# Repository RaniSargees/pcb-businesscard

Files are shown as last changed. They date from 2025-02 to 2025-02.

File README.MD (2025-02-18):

# PCB BUSINESS CARD

this project is a business card made of a circuit board with an 11x10 charlieplexed LED display.

The circuit board uses special construction techniques to achieve minimum thickness, such as mounting every component upside-down, through drilled holes.

this project is based on the HK32F030M microcontroller, which is obscure and poorly-documented (in english, at least), but very inexpensive

the total cost per card (purchased in medium-low volume) is ~$0.80CAD, which is high for a business card but still relatively cheap

# INCOMPLETE FIRMWARE

the firmware for this project is incomplete. the breakout game is unfinished, and I haven't even began working on pong, space invaders, and other games i wanted to add.

also, the font is a little unreadable on the display, which sort of defeats the purpose of this business card. I probably should have included my name and email in the silkscreen

---

still, uploading this for reference, perhaps someone can use this project as an example of how to set up keil for the hk32. that chip doesn't have much documentation, it seems everyone went for the risc-v based budget microcontrollers and not the ARM-based HK32 or PY32

# IMAGES

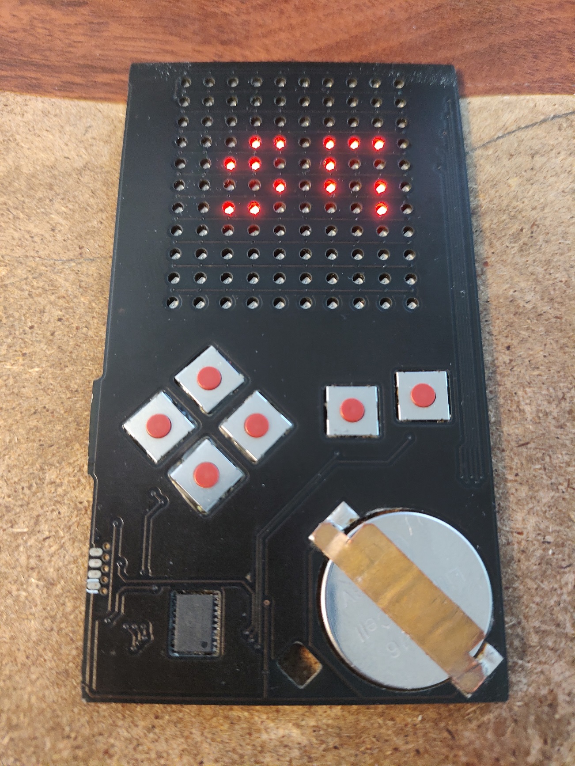
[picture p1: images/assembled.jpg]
assembled


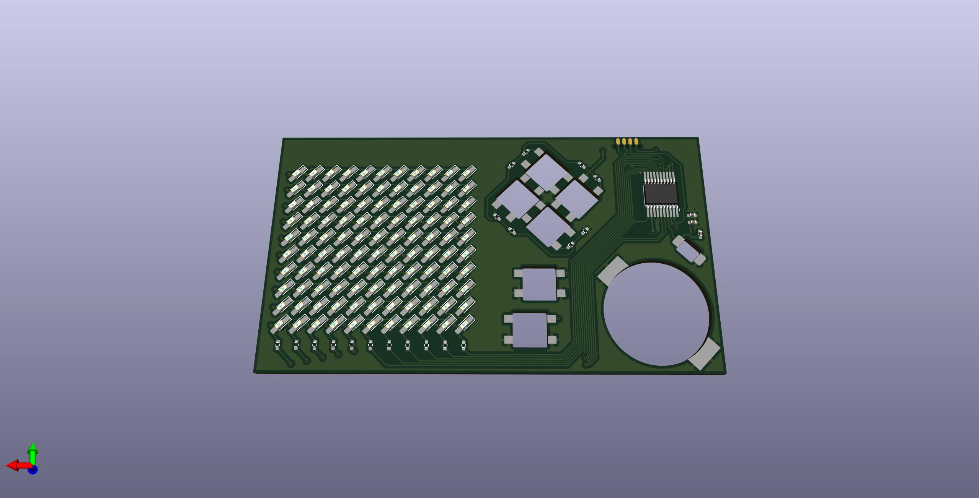
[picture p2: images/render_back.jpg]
back


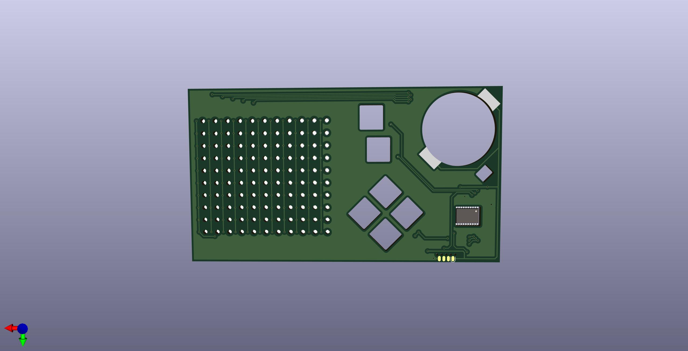
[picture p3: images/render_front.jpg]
front


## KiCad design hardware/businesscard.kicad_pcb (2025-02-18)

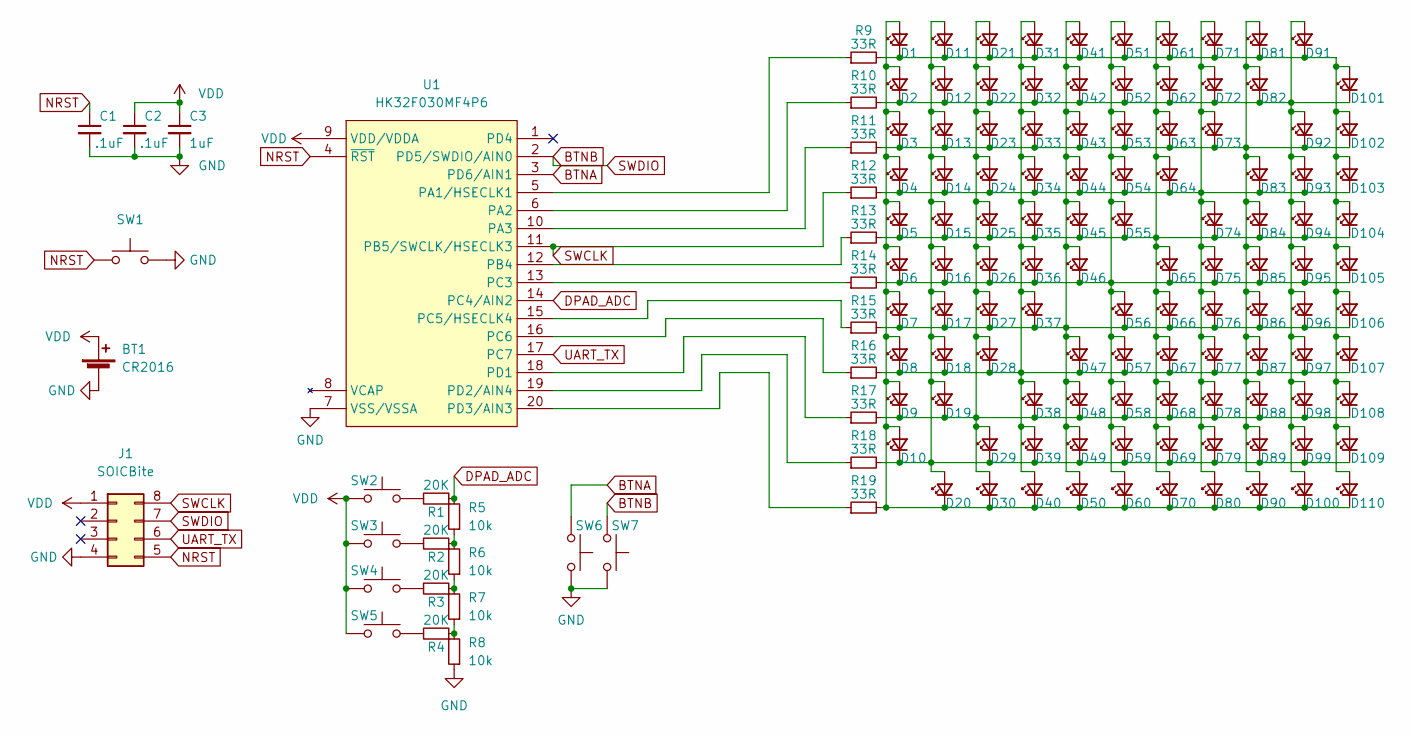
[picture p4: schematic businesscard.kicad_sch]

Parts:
BT1: CR2016; cr2016
C1, C2: .1uF; C_0402_1005Metric_Pad0.74x0.62mm_HandSolder
C3: 1uF; C_0402_1005Metric_Pad0.74x0.62mm_HandSolder
D1, D2, D3, D4, D5, D6, D7, D8, D9, D10, D11, D12, D13, D14, D15, D16, D17, D18, D19, D20, D21, D22, D23, D24, D25, D26, D27, D28, D29, D30, D31, D32, D33, D34, D35, D36, D37, D38, D39, D40, D41, D42, D43, D44, D45, D46, D47, D48, D49, D50, D51, D52, D53, D54, D55, D56, D57, D58, D59, D60, D61, D62, D63, D64, D65, D66, D67, D68, D69, D70, D71, D72, D73, D74, D75, D76, D77, D78, D79, D80, D81, D82, D83, D84, D85, D86, D87, D88, D89, D90, D91, D92, D93, D94, D95, D96, D97, D98, D99, D100, D101, D102, D103, D104, D105, D106, D107, D108, D109, D110: LED_Small; LED_0603_1608Metric_Pad1.05x0.95mm_HandSolder
J1: SOICBite; SOIC_clipProgSmall
R1, R2, R3, R4: 20K; R_0402_1005Metric_Pad0.72x0.64mm_HandSolder
R5, R6, R7, R8: 10k; R_0402_1005Metric_Pad0.72x0.64mm_HandSolder
R9, R10, R11, R12, R13, R14, R15, R16, R17, R18, R19: 33R; R_0402_1005Metric_Pad0.72x0.64mm_HandSolder
SW1: SW_Push; SW_3x4x2
SW2, SW3, SW4, SW5, SW6, SW7: SW_Push; SW_SPST_TSE024
U1: HK32F030MF4P6; TSSOP-20_4.4x6.5mm_P0.65mm

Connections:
BTNA: SW6.2, U1.3 (PD6/AIN1)
DPAD_ADC: R1.1, R5.2, U1.14 (PC4/AIN2)
GND: BT1.2 (-), C1.2, C2.2, C3.2, J1.4, R8.1, SW1.2, SW6.1, SW7.1, U1.7 (VSS/VSSA)
NRST: C1.1, J1.5, SW1.1, U1.4 (~RST)
unnamed: D1.1 (K), D11.1 (K), D21.1 (K), D31.1 (K), D41.1 (K), D51.1 (K), D61.1 (K), D71.1 (K), D81.1 (K), D91.1 (K), D101.2 (A), D102.2 (A), D103.2 (A), D104.2 (A), D105.2 (A), D106.2 (A), D107.2 (A), D108.2 (A), D109.2 (A), D110.2 (A), R9.2
unnamed: D1.2 (A), D2.2 (A), D3.2 (A), D4.2 (A), D5.2 (A), D6.2 (A), D7.2 (A), D8.2 (A), D9.2 (A), D10.2 (A), D20.1 (K), D30.1 (K), D40.1 (K), D50.1 (K), D60.1 (K), D70.1 (K), D80.1 (K), D90.1 (K), D100.1 (K), D110.1 (K), R19.2
unnamed: D10.1 (K), D11.2 (A), D12.2 (A), D13.2 (A), D14.2 (A), D15.2 (A), D16.2 (A), D17.2 (A), D18.2 (A), D19.2 (A), D20.2 (A), D29.1 (K), D39.1 (K), D49.1 (K), D59.1 (K), D69.1 (K), D79.1 (K), D89.1 (K), D99.1 (K), D109.1 (K), R18.2
unnamed: D2.1 (K), D12.1 (K), D22.1 (K), D32.1 (K), D42.1 (K), D52.1 (K), D62.1 (K), D72.1 (K), D82.1 (K), D91.2 (A), D92.2 (A), D93.2 (A), D94.2 (A), D95.2 (A), D96.2 (A), D97.2 (A), D98.2 (A), D99.2 (A), D100.2 (A), D101.1 (K), R10.2
unnamed: D3.1 (K), D13.1 (K), D23.1 (K), D33.1 (K), D43.1 (K), D53.1 (K), D63.1 (K), D73.1 (K), D81.2 (A), D82.2 (A), D83.2 (A), D84.2 (A), D85.2 (A), D86.2 (A), D87.2 (A), D88.2 (A), D89.2 (A), D90.2 (A), D92.1 (K), D102.1 (K), R11.2
unnamed: D4.1 (K), D14.1 (K), D24.1 (K), D34.1 (K), D44.1 (K), D54.1 (K), D64.1 (K), D71.2 (A), D72.2 (A), D73.2 (A), D74.2 (A), D75.2 (A), D76.2 (A), D77.2 (A), D78.2 (A), D79.2 (A), D80.2 (A), D83.1 (K), D93.1 (K), D103.1 (K), R12.2
unnamed: D5.1 (K), D15.1 (K), D25.1 (K), D35.1 (K), D45.1 (K), D55.1 (K), D61.2 (A), D62.2 (A), D63.2 (A), D64.2 (A), D65.2 (A), D66.2 (A), D67.2 (A), D68.2 (A), D69.2 (A), D70.2 (A), D74.1 (K), D84.1 (K), D94.1 (K), D104.1 (K), R13.2
unnamed: D6.1 (K), D16.1 (K), D26.1 (K), D36.1 (K), D46.1 (K), D51.2 (A), D52.2 (A), D53.2 (A), D54.2 (A), D55.2 (A), D56.2 (A), D57.2 (A), D58.2 (A), D59.2 (A), D60.2 (A), D65.1 (K), D75.1 (K), D85.1 (K), D95.1 (K), D105.1 (K), R14.2
unnamed: D7.1 (K), D17.1 (K), D27.1 (K), D37.1 (K), D41.2 (A), D42.2 (A), D43.2 (A), D44.2 (A), D45.2 (A), D46.2 (A), D47.2 (A), D48.2 (A), D49.2 (A), D50.2 (A), D56.1 (K), D66.1 (K), D76.1 (K), D86.1 (K), D96.1 (K), D106.1 (K), R15.2
unnamed: D8.1 (K), D18.1 (K), D28.1 (K), D31.2 (A), D32.2 (A), D33.2 (A), D34.2 (A), D35.2 (A), D36.2 (A), D37.2 (A), D38.2 (A), D39.2 (A), D40.2 (A), D47.1 (K), D57.1 (K), D67.1 (K), D77.1 (K), D87.1 (K), D97.1 (K), D107.1 (K), R16.2
unnamed: D9.1 (K), D19.1 (K), D21.2 (A), D22.2 (A), D23.2 (A), D24.2 (A), D25.2 (A), D26.2 (A), D27.2 (A), D28.2 (A), D29.2 (A), D30.2 (A), D38.1 (K), D48.1 (K), D58.1 (K), D68.1 (K), D78.1 (K), D88.1 (K), D98.1 (K), D108.1 (K), R17.2
unnamed: R1.2, SW2.1
unnamed: R2.2, SW3.1
unnamed: R3.2, SW4.1
unnamed: R4.2, SW5.1
unnamed: R2.1, R5.1, R6.2
unnamed: R3.1, R6.1, R7.2
unnamed: R4.1, R7.1, R8.2
unnamed: R9.1, U1.5 (PA1/HSECLK1)
unnamed: R10.1, U1.6 (PA2)
unnamed: R11.1, U1.10 (PA3)
unnamed: R13.1, U1.12 (PB4)
unnamed: R14.1, U1.13 (PC3)
unnamed: R15.1, U1.15 (PC5/HSECLK4)
unnamed: R16.1, U1.16 (PC6)
unnamed: R17.1, U1.18 (PC1)
unnamed: R18.1, U1.19 (PD2/AIN4)
unnamed: R19.1, U1.20 (PD3/AIN3)
SWCLK: J1.8, R12.1, U1.11 (PB5/SWCLK/HSECLK3)
SWDIO: J1.7, SW7.2, U1.2 (PD5/SWDIO/AIN0)
UART_TX: J1.6, U1.17 (PC7)
VDD: BT1.1 (+), C2.1, C3.1, J1.1, SW2.2, SW3.2, SW4.2, SW5.2, U1.9 (VDD/VDDA)

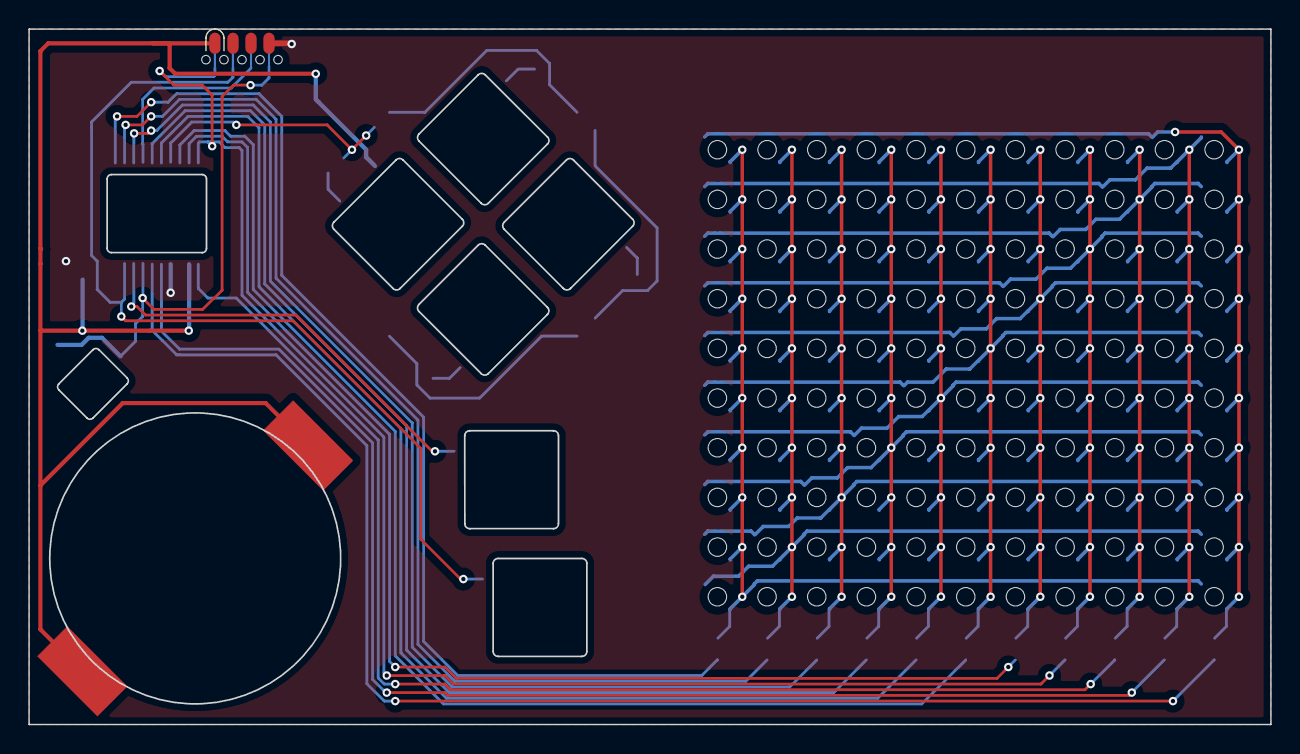
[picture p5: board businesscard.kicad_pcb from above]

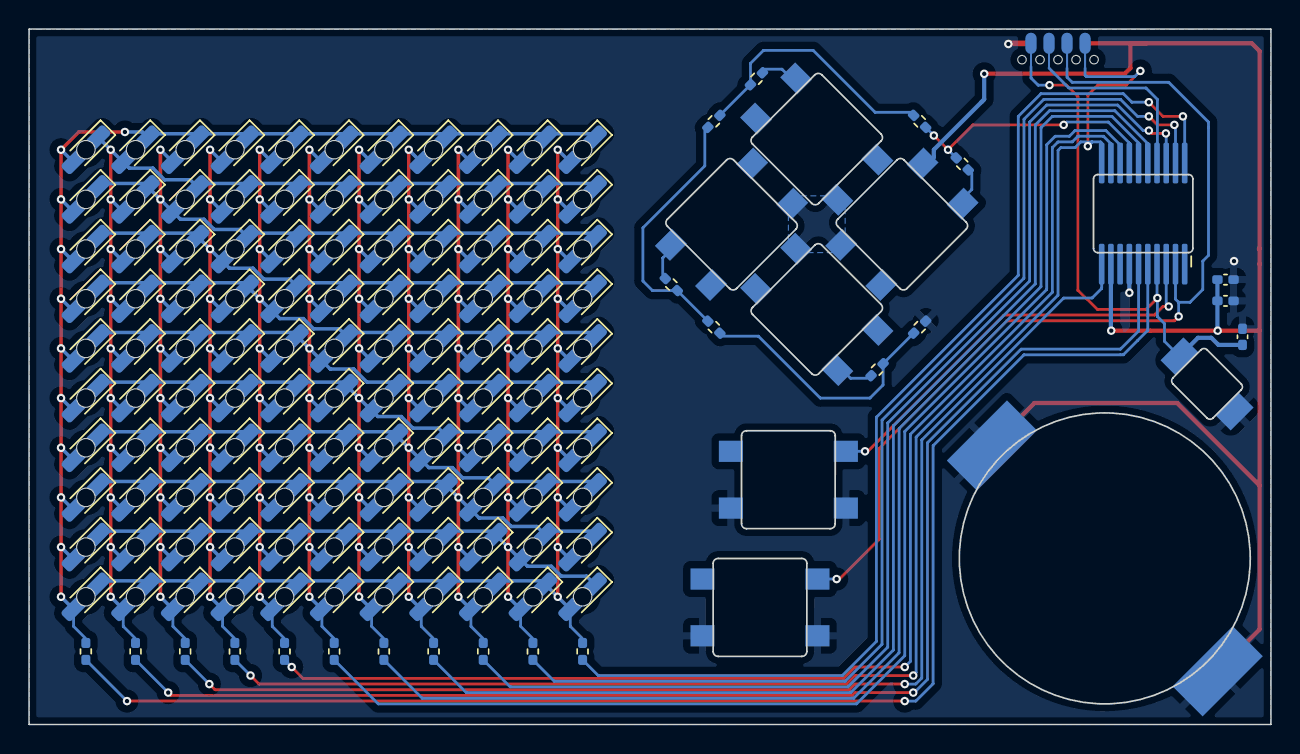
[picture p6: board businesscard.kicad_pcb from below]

Board: 2 copper layers, 87.5 x 49.0 mm, 142 parts (22 on the bottom side), 36 nets.

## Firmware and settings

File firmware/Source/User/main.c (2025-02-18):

#include "hardware.h"
#include "games.h"
#include "intro.h"
#include "snake.h"

#include "drawing.h"
#include <hk32f030m.h>

extern uint8_t buttons;
extern uint8_t button_change;

#define PADDLE_WIDTH 3
#define PADDLE_SPEED_ADJ 4

#define BALL_SPEED_ADJ 3

extern uint16_t framebuffer[DISPLAY_HEIGHT];

void breakout() {
	uint8_t ball_x = (DISPLAY_WIDTH << BALL_SPEED_ADJ) / 2;
	uint8_t ball_y = (DISPLAY_HEIGHT - 2) << BALL_SPEED_ADJ;
	int8_t ball_vspeed = -1;
	int8_t ball_hspeed = 1;
	uint8_t paddle_pos = (DISPLAY_WIDTH << PADDLE_SPEED_ADJ) / 2 - (PADDLE_WIDTH << PADDLE_SPEED_ADJ) / 2;
	uint8_t temp1;
	uint8_t temp2;
	
	uint8_t bricks[DISPLAY_HEIGHT / 2 - 1][DISPLAY_WIDTH / 2] = {{0}};
	
	while (1) {
		update_buttons();
		
		//move paddle
		if (buttons & 0b001000) { //left
			if (paddle_pos > 0) {
				--paddle_pos;
			}
		} else if (buttons & 0b000100) { //right
			if ((paddle_pos >> PADDLE_SPEED_ADJ) < (DISPLAY_WIDTH - PADDLE_WIDTH)) {
				++paddle_pos;
			}
		}

		//bounce off sides
		if (((ball_x + ball_hspeed) >> BALL_SPEED_ADJ) >= DISPLAY_WIDTH) {
			ball_hspeed *= -1;
		}

		//bounce off ceiling
		if (ball_y == 0 && ball_vspeed < 0) {
			ball_vspeed *= -1;
		}

		//bounce off the paddle, angle dependent on paddle position
		//this is super complicated because the ball and paddle actually work in
		//different coordinate spaces; the paddle having double the range of the
		//ball. That's how the speed adjustment is handled. it works ¯\_(''/)_/¯
		if (((ball_y + ball_vspeed) >> BALL_SPEED_ADJ) == (DISPLAY_HEIGHT - 1)
		&& (ball_x + ball_hspeed) >= (paddle_pos >> (PADDLE_SPEED_ADJ - BALL_SPEED_ADJ))
		&& (ball_x + ball_hspeed) <= ((paddle_pos + (PADDLE_WIDTH << PADDLE_SPEED_ADJ))
		>> (PADDLE_SPEED_ADJ - BALL_SPEED_ADJ))) {
			ball_vspeed *= -1;
			ball_hspeed = (5 *((ball_x - (paddle_pos >> (PADDLE_SPEED_ADJ - BALL_SPEED_ADJ)))) / (PADDLE_WIDTH << BALL_SPEED_ADJ)) - 2;
		}

		//check for bricks
		temp1 = (ball_y + ball_vspeed) >> BALL_SPEED_ADJ;
		if (temp1 <= (DISPLAY_HEIGHT / 2 - 1)
		&& !bricks[temp1][(temp2=((ball_x + ball_hspeed) >> (BALL_SPEED_ADJ + 1)))]) {
			bricks[temp1][temp2] = 1;
		}
		
		//move ball
		ball_x += ball_hspeed;
		ball_y += ball_vspeed;


		if ((ball_y >> BALL_SPEED_ADJ) >= DISPLAY_HEIGHT) {
			break; //end the game
		}

		//drawing
		clear_framebuffer();

		draw_dot(ball_x >> BALL_SPEED_ADJ, ball_y >> BALL_SPEED_ADJ);

		draw_line(paddle_pos >> PADDLE_SPEED_ADJ, DISPLAY_HEIGHT - 1, PADDLE_WIDTH, right);

		for (uint8_t i = 0; i<DISPLAY_HEIGHT / 2 - 1; ++i) {
			for (uint8_t j = 0; j<DISPLAY_WIDTH / 2; ++j) {
				if (!bricks[i][j]) {
					draw_dot(j << 1, i);
					draw_dot((j << 1) + 1, i);
				}
			}
		}
		update_screen();
	}

	//reuse this variable for delay
	paddle_pos = 200;

	//invert the framebuffer
	for(uint8_t i = 0; i<DISPLAY_HEIGHT; ++i) {
		blit_line(i, 0xffff, ~framebuffer[i]);
	}

	//display end screen
	while(paddle_pos--) {
		update_screen();
	}
}

void pong() {

}

int main(void) {
	//bare minimum to be able to wake up from sleep on a button press
	init_gpio_clocks();
	init_button_gpios();
	
	//this is the "power off" mode, since there is no power switch
	sleep();
	
	//the rest (LED GPIOs and ADC)
	init_matrix_gpios();
	init_dpad_gpio();
	
	while (1) {
		switch(intro()) {
			case game_snake:
				snake();
				break;
			case game_breakout:
				breakout();
				break;
			case game_pong:
				pong();
				break;
			case game_none:
				break;
		}
	}
}

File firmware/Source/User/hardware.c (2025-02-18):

#include "hk32f030m.h" 
#include "hk32f030m_it.h" 
#include "hk32f030m_pwr.h"
#include "hk32f030m_exti.h"
#include "hardware.h"

//buttons are stored in one byte, pattern 0b00UDLRBA
//with only one directional key permitted at a time
uint8_t buttons = 0;
uint8_t button_change = 0;

uint8_t analog  = 0;

void Delay(__IO uint32_t nCount) { //simple delay function
	for(; nCount != 0; nCount--);
}

uint16_t matrix_pins[11] = {
	GPIO_Pin_1,
	GPIO_Pin_2,
	GPIO_Pin_3,
	GPIO_Pin_4,
	GPIO_Pin_4,
	GPIO_Pin_3,
	GPIO_Pin_5,
	GPIO_Pin_6,
	GPIO_Pin_1,
	GPIO_Pin_2,
	GPIO_Pin_3,
};
GPIO_TypeDef * matrix_ports[11] = {
	GPIOA,
	GPIOA,
	GPIOA,
	GPIOD,
	GPIOB,
	GPIOC,
	GPIOC,
	GPIOC,
	GPIOD,
	GPIOD,
	GPIOD,
};

void set_gpio_mode(GPIO_TypeDef *port, uint16_t pin, GPIOMode_TypeDef mode) {
	/*-- GPIO Mode Configuration --*/
	uint32_t pinpos = 0x00, pos = 0x00 , currentpin = 0x00;

  for (pinpos = 0x00; pinpos < 0x10; pinpos++) {
    pos = ((uint32_t)0x01) << pinpos;

    /* Get the port pins position */
    currentpin = (pin) & pos;

    if (currentpin == pos) {
      port->MODER  &= ~(GPIO_MODER_MODER0 << (pinpos * 2));
      port->MODER |= (((uint32_t)mode) << (pinpos * 2));
    }
  }
}

void init_gpio_clocks() {
	RCC_AHBPeriphClockCmd( RCC_AHBPeriph_GPIOA, ENABLE);
	RCC_AHBPeriphClockCmd( RCC_AHBPeriph_GPIOB, ENABLE);
	RCC_AHBPeriphClockCmd( RCC_AHBPeriph_GPIOC, ENABLE);
	RCC_AHBPeriphClockCmd( RCC_AHBPeriph_GPIOD, ENABLE);
}

void init_matrix_gpios() {	
	GPIO_InitTypeDef GPIO_InitStructure;
	
	GPIO_InitStructure.GPIO_Mode  = GPIO_Mode_OUT; //output
	GPIO_InitStructure.GPIO_OType = GPIO_OType_PP; //push-pull
	GPIO_InitStructure.GPIO_Speed = GPIO_Speed_10MHz; //slow

	for (uint8_t i = 0; i<11; ++i) {
		GPIO_InitStructure.GPIO_Pin = matrix_pins[i];
		GPIO_Init(matrix_ports[i], &GPIO_InitStructure); //initialize
		GPIO_ResetBits(matrix_ports[i], matrix_pins[i]); //clear
		set_gpio_mode(matrix_ports[i], matrix_pins[i], GPIO_Mode_IN); //change to high-Z (input)
	}
}

void init_button_gpios() {
	GPIO_InitTypeDef GPIO_InitStructure;

	GPIO_InitStructure.GPIO_Mode = GPIO_Mode_IN;
	GPIO_InitStructure.GPIO_PuPd = GPIO_PuPd_UP;
	GPIO_InitStructure.GPIO_Speed= GPIO_Speed_10MHz;
	
	GPIO_InitStructure.GPIO_Pin = btnA_pin;
	GPIO_Init(btnA_port, &GPIO_InitStructure);
	GPIO_InitStructure.GPIO_Pin = btnB_pin;
	GPIO_Init(btnB_port, &GPIO_InitStructure);
}

void init_dpad_gpio() {
	//adc gpio config
	GPIO_InitTypeDef GPIO_InitStructure;
	
	GPIO_InitStructure.GPIO_Mode = GPIO_Mode_AN;
	GPIO_InitStructure.GPIO_Speed = GPIO_Speed_10MHz;
	
	GPIO_InitStructure.GPIO_Pin = dpad_pin;
	GPIO_Init(dpad_port, &GPIO_InitStructure);
	
	//adc mode config
	RCC_APB2PeriphClockCmd ( RCC_APB2Periph_ADC, ENABLE );	
	ADC_DeInit(dpad_adc);
	
	ADC_InitTypeDef ADC_InitStructure;
	ADC_StructInit(&ADC_InitStructure);
	
	ADC_InitStructure.ADC_ContinuousConvMode = ENABLE;
	ADC_InitStructure.ADC_ExternalTrigConv = ADC_ExternalTrigConvEdge_None;
	ADC_InitStructure.ADC_DataAlign = ADC_DataAlign_Right;
	ADC_InitStructure.ADC_ScanDirection = ADC_ScanDirection_Upward;
	
	ADC_Init(dpad_adc,&ADC_InitStructure);
	
	ADC_ChannelConfig(dpad_adc, dpad_adc_channel , ADC_SampleTime_239_5Cycles);
	ADC_GetCalibrationFactor(dpad_adc);
	ADC_Cmd(dpad_adc, ENABLE);
	
	while(!ADC_GetFlagStatus(dpad_adc, ADC_FLAG_ADRDY));
	
	ADC_StartOfConversion(dpad_adc);
}

void control_matrix_led(uint8_t x, uint8_t y, uint8_t on) {
	static uint8_t current_x = 0;
	static uint8_t current_y = 0;
	
	if (x >= y){++x;} //charlieplexing is fun!

	//reset previous light gpio
	GPIO_ResetBits(matrix_ports[current_x], matrix_pins[current_x]);
	GPIO_ResetBits(matrix_ports[current_y], matrix_pins[current_y]);
	
	//set previous light gpio to high-Z
	set_gpio_mode(matrix_ports[current_x], matrix_pins[current_x], GPIO_Mode_IN);
	set_gpio_mode(matrix_ports[current_y], matrix_pins[current_y], GPIO_Mode_IN);
	
	//update current gpios
	current_x = x;
	current_y = y;
	
	if (!on) {return;}
	
	//set new light gpio to output
	set_gpio_mode(matrix_ports[x], matrix_pins[x], GPIO_Mode_OUT);
	set_gpio_mode(matrix_ports[y], matrix_pins[y], GPIO_Mode_OUT);
	
	//place positive voltage on y line, ground on x line
	digitalLo(matrix_ports[x], matrix_pins[x]);
	digitalHi(matrix_ports[y], matrix_pins[y]);
}

void update_buttons() {
	uint8_t old = buttons;
	
	buttons = (~digitalRead(btnA) & 0b1);
	buttons|= (~digitalRead(btnB) & 0b1) << 1;
		
	if (ADC_GetFlagStatus(dpad_adc, ADC_FLAG_EOC)) {
		ADC_ClearFlag(dpad_adc, ADC_FLAG_EOC);
		analog = (uint8_t) (ADC_GetConversionValue(dpad_adc) >> 7);
			
		buttons |= ((analog & 0b11110) == 0b10000) << 5; //up
		buttons |= ((analog & 0b11111) == 0b01111) << 5; //up again (it's marginal)
		buttons |= ((analog & 0b11111) == 0b10101) << 4; //down
		buttons |= ((analog & 0b11110) == 0b10010) << 3; //left
		buttons |= ((analog & 0b11110) == 0b01010) << 2; //right
	}
	
	button_change = old ^ buttons;
}
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

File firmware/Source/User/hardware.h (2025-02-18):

#ifndef __HARDWARE_H
#define __HARDWARE_H
#ifdef __cplusplus
extern "C" {
#endif
	
#include "hk32f030m.h" 
	
#define SOFT_DELAY  Delay(0x0FFFFF);
#define SOFT_DELAY_SHORT  Delay(0x0FFFF);
#define SOFT_DELAY_VERY_SHORT Delay(0x0FFF);
#define SOFT_DELAY_EXTREMELY_SHORT Delay(0x080);

/* The method of directly manipulating registers controls IO */
#define	digitalHi(p,i)		 {p->BSRR=i;}	 //output is high		
#define digitalLo(p,i)		 {p->BRR=i;}	 //output is low
#define digitalToggle(p,i) {p->ODR ^=i;} //toggle the output
#define digitalRead GPIO_ReadInputDataBit

//pin definitions
#define btnA_pin GPIO_Pin_6
#define btnB_pin GPIO_Pin_5

#define btnA_port GPIOD
#define btnB_port GPIOD

#define btnA btnA_port,btnA_pin
#define btnB btnB_port,btnB_pin

#define btnA_EXTI_port EXTI_PortSourceGPIOD
#define btnB_EXTI_port EXTI_PortSourceGPIOD

#define btnA_EXTI_pin GPIO_PinSource6
#define btnB_EXTI_pin GPIO_PinSource5

#define dpad_pin GPIO_Pin_4
#define dpad_port GPIOC
#define dpad_adc ADC1
#define dpad_adc_channel ADC_Channel_2
#define dpad_adc_irq ADC1_IRQn
#define dpad_adc_irq_handler ADC1_IRQHandler

void Delay(__IO uint32_t nCount);

void set_gpio_mode(GPIO_TypeDef *port, uint16_t pin, GPIOMode_TypeDef mode);

void init_gpio_clocks();

void init_matrix_gpios();

void init_button_gpios();

void init_dpad_gpio();

void control_matrix_led(uint8_t x, uint8_t y, uint8_t on);

void update_buttons();

void sleep();

#ifdef __cplusplus
}
#endif
#endif
